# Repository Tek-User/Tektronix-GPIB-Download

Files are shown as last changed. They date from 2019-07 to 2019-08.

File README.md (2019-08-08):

# Tektronix-GPIB-Download
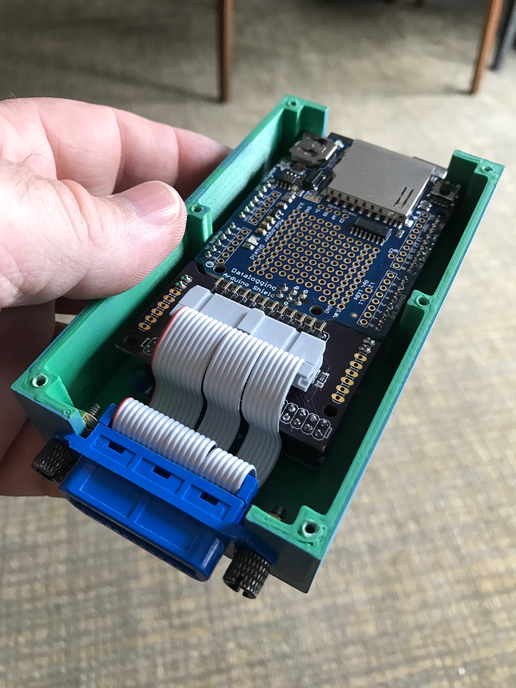
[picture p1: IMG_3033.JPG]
<a href="https://github.com/Tek-User/Tektronix-GPIB-Download/blob/master/IMG_3033.JPG"><br/></a>
 
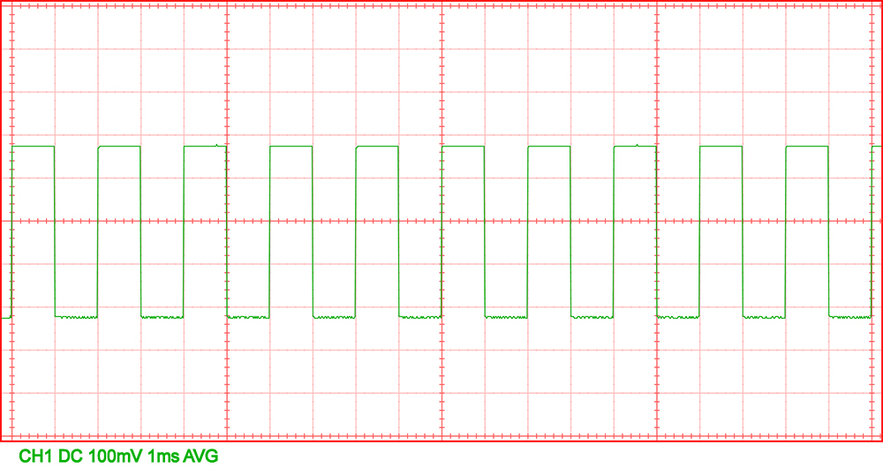
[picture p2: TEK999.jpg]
 <a href="https://github.com/Tek-User/Tektronix-GPIB-Download/blob/master/TEK999.jpg"><br/></a>

Software (and hardware) to allow copying your oscilloscope display directly to a flash drive using an Arduino Mega256

This purpose of this project is to create an inexpensive, and simple-to-build device which attaches to Tektronix 2430, 2430A, 2432, and 2440 digital storage oscilloscopes via GPIB interface to allow the user to download the displayed trace(s) to a flash drive without the need for a computer to be attached to the oscilloscope.  No hardware beyond the device and a GPIB cable are required.  The downloaded file on the flash drive is a vector graphics file type (SVG) which can be viewed and printed using readily available free software, even most web browsers.  

An Arduino (or clone) Mega2560 is required as the smaller devices do not have enough I/O pins to do the job properly.

The program interfaces to the oscilloscope front panel user-interface buttons.  It will save the displayed traces to a SVG file along with the volts/div and sec/div settings.  All 1024 data points are stored in the vector graphics file.

Control menus allow storing the trace(s), setting date/time/filename.

About 11% of the arduino flash is used, and 2K of the 8K ram is used allowing ample space for additions and modifications of the code to suit individual needs.  

The RTC and SD functions are provided by the Adafruit SD datalogging shield:
https://tinyurl.com/yyhj2fle

The device uses a custom "mini-shield" to connect to the Arduino Mega double row expansion connector, and provides a 24 pin (2x12) connector to go to a GPIB connector.  The link to the custom PCB on OSHPARK is :
https://oshpark.com/shared_projects/mtz1Vv3A

To build the GPIB mini-shield use sixteen 470 ohm 1206 size SMT resistors, a 2x18 straight male header (for the Arduino expansion header), and a 2x12 right angle (or straight) male header for the GPIB connector, and two 1x2 male headers. The 1x2 headers only provide some extra stability for the board in its attachment to the Arduino Mega.  If you use feed-through stacking headers, you can add more shields on top of this one.

An enclosure is able to be 3D printed.  The enclosure design (STL file type) is included in this project.  There are two separate files, one being the top and one being the bottom of the enclosure.  Some final fine-tuning of the enclosure is likely to be needed to get a perfect fit.  Use a fine file intended for woodworking.  In some places sandpaper will work well too.

Photos are included of the project (the enclosure, and resistor location on the mini-shield PCB are slightly different from the final designs in this project).  There is also a photo of an SVG file which has been converted to a raster JPG to display here.

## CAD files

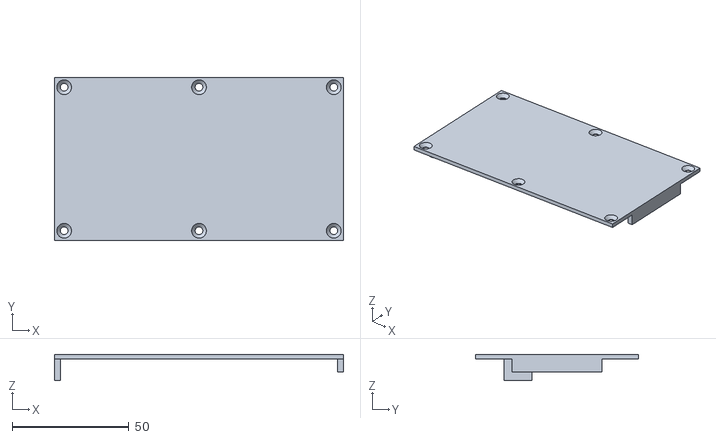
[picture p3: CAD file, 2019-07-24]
Arduino_GPIB_Box-top.stl
124.0 x 69.9 x 11.2

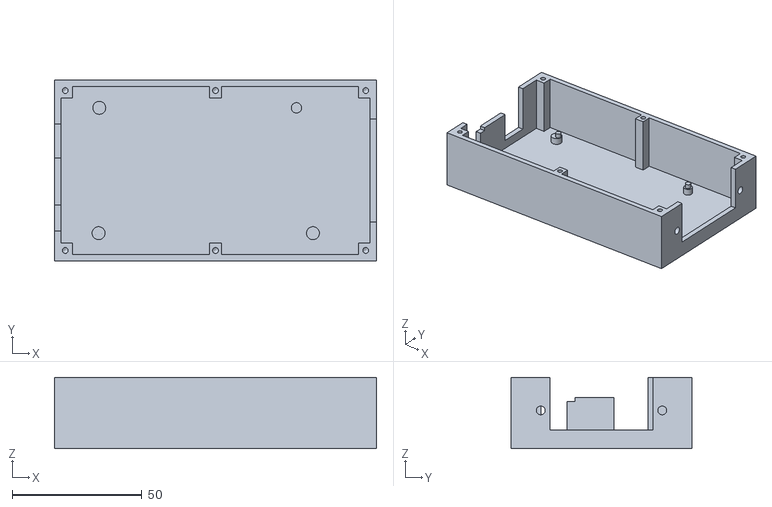
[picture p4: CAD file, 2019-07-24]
Arduino_GPIB_Box-bottom.stl
124.0 x 69.9 x 27.4

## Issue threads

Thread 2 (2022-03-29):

PCB layout differs from photo

algavrik, 2022-03-29:
PCB layout on OSHPARK differs from the real photo of PCB in the project. On OSHPARK PCB resistors are on the bottom side (arduino) of the board, but on the real photo I can see resistors on the top side of PCB (GPIB). Can you clarify?

Tek-User, 2022-03-29:
I will check.  It has been a couple of years since I worked with this.

-Tony

Sent from my 1837 Babbage Analytical Engine

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

Tek-User, 2023-11-01:
The through hole resistors can be placed on either side.   For simplicity during design I drew everything on the same side but for construction they can be placed on either side

Closed 2023-11-01.

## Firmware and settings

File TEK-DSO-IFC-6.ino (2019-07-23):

#include <avr/pgmspace.h>
#include <stdlib.h>
#include <inttypes.h>
#include <stdint.h>
#include <stdbool.h>
#include "GPIB.h"
#include "Tek_Interface.h"
#include "SVG.h"
#include "Arduino.h"
#include "RTC.h"
#include "EEP.h"
#include <SD.h>
#include <SPI.h>


/*This code will interface to the scope and wait for a SRQ.  It assumes it is ONLY connected to one scope and
 * nothing else.  It does not poll "EVT?"   It simply uses a loop reading the SRQ signal and when it is asserted (LOW)
 * it will read the event and take appropriate action.
 * 
 * There are 5 buttons that are able to be used: event code 450-454 inclusive
 * 1:  Save displayed waveforms to SVG
 * 2:  unused:  Maybe something like FFT
 * 3:  unused:  Maybe to save the front panel setup
 * 4:  unused:  Maybe something like recall the front panel setup
 * 5:  unused:  Use it for a hard reboot of the arduino
 * 
 *   This will not use the switches on the modified SONY-TEKTRONIX unit: the box is passive 
 *   This allows essentially ANY ARDUINO to be used for the GPIB interface as long as it can also use an SD card somehow.
 *   I think that NANO types don't have enough IO pins for full GPIB interface plus SD
 */


/*   Assumes the scope is at address #1! */


// TODO:  have errors printed to the scope screen instead of to the serial port


//extern char data_buffer[];  //defined in Tek_Interface module
extern RTC_PCF8523 rtc;



void setup() {

  
  bool wait_for_scope_boot = false;
  Serial.begin(115200);

 
  Serial.print(F("checking bus"));
  while (!GPIBCheck()) {   //check the GPIB Bus
      //TODO:  send message to 7-segments "SCOP" to indicate no scope present.  OR scroll "NO SCOPE" on the display
      delay(1000);
      Serial.print(F("."));
      wait_for_scope_boot = true;
  }
  Serial.println(F(" Bus OK"));
  

  //if the bus was not on-line when first tested, then the scope is booting up
  // and we need to it for the scope to complete its own initialization 
  if (wait_for_scope_boot)
  {
      Serial.println(F("Scope Boot Delay...30 sec"));
    for (int i=0; i<30;i++) //perform N loops of a 1 second delay
    {
      delay(1000);  //delay 1 second
    }
  }


  EEP_Init();
  RTC_setup();

  DateTime now = rtc.now();
    Serial.print(now.year(), DEC);
    Serial.print('/');
    Serial.print(now.month(), DEC);
    Serial.print('/');
    Serial.println(now.day(), DEC);

    Serial.print(now.hour(), DEC);
    Serial.print(':');
    Serial.print(now.minute(), DEC);
    Serial.print(':');
    Serial.print(now.second(), DEC);
    Serial.println();

    
  tek_Setup();

  checkID(); //TODO: use this check to stop further processing?
  introScreen();
  
  tek_Menu(1); 



  //testDataPins();
  //testSPI();
}




//******************************************************************************
void loop() {
  uint16_t event;


  event = 0;

#ifdef USE_SRQ  
//  Serial.println(F("wait for SRQ"));

  while (WaitForSRQ(0, 0xFFFE));  //returns a 1 if timeout occurs.  Keep polling SRQ until it is asserted (LOW): returns before timeout with a value of zero.
  
//    if (SRQ_PIN & SRQ_BIT) Serial.print(F("SRQ NOT ASSERTED (high)"));
//    else Serial.print(F("SRQ IS ASSERTED (low)"));
  event = GetEvent_SRQ();
  if (event) 
  {
    Serial.print(F("Event occurred:"));
    Serial.println(event);
    processEvent(event);
  }
  //no delays: process SRQs as fastr as possible

#else //use polling method
  event = GetEvent();
  if (event) 
  {
    Serial.print(F("Event occurred:"));
    Serial.println(event);
    processEvent(event);
  }
  else delay(1000); //if there is an event read, then don't delay reading the next one in case they are stacked up

#endif
 
}  //end of loop









//*********************************************************
//*
//*  Handle an incoming event
//*     Most will just get ignored!
//*
//*********************************************************
void processEvent(uint16_t evnt)
{
  // main menu [0] = save svg/hide/x/settings/reset cpu
  // settings menu [1] = date/time/x/x/back
  static uint8_t MenuState = 0;

  switch (MenuState)
  {
    case 0: //main menu
     switch (evnt)
     {
       case 652:  //hide display button pressed
         tek_Menu(MenuState, 1);  //show the menu and force it to be displayed
         break;
       case 450:  //Left hand-most button pressed:  save SVG
         processSVG();
         break;
       case 451:   //hide or unhide the menubar
         tek_Menu(MenuState);  //toggle the displayed state of the menu
         break;
       case 452:
         break;
       case 453:
         MenuState = 1;
         tek_Menu(MenuState,1); //show the new menu and force it to be displayed
         break;
       case 454: //maybe use this to hard reset the arduino
         //hideMenu();
         resetCPU();
         break;
      }  //end switch evnt
      break;

    case 1: //settings menu
     switch (evnt)
     {
       case 652:  //hide display button pressed
         tek_Menu(MenuState, 1);  //show the menu and force it to be displayed
         break;
       case 450:  //set date
         //call date setting function
         RTC_Date();
         tek_Menu(MenuState, 1);  //show the menu and force it to be displayed
         break;
       case 451: //set time
         RTC_Time();
         tek_Menu(MenuState, 1);  //show the menu and force it to be displayed
         break;
       case 452: //set file name
         tek_SetFileName();
         tek_Menu(MenuState, 1);  //show the menu and force it to be display
         break;
       case 453:
         break;
       case 454: //move up one menu state
         MenuState--;
         if (MenuState == 0xFF) MenuState = 0; //prevent undershooting menustate accidentally: shouldn't ever be possible
         tek_Menu(MenuState,1); //show the new menu and force it to be displayed
         break;
      }  //end switch evnt
      break;
  }  //end switch MenuState  
}




void resetCPU(void)
{
  //This does a software-only reset without resetting ALL the hardware
  //void(* resetFunc) (void) = 0;//declare reset function at address 0
  //resetFunc(); //call reset 

  //This does a hardware reset like a power-up reset:  All registers ad pins are cleared

  noInterrupts();
  __asm("wdr");
  WDTCSR = (1<<WDCE) | (1<<WDE);
  WDTCSR = (1<<WDE);
  while (1);
}












void testDataPins(void)
{
    Serial.println(F("testing pins: data0, gpib PIN 1"));
    //test the data pins
     while (Serial.available()) Serial.read();   //flush the serial channel
     while (!Serial.available()) {
        GPIBRelease( &DATA0_PORT,&DATA0_DDR, DATA0_BIT);
        delay(10);
        GPIBAssert( &DATA0_PORT,&DATA0_DDR, DATA0_BIT);
        delay(10);
     }

     while (Serial.available()) Serial.read();   //flush the serial channel

     Serial.println(F("testing pins: data1, GPIB PIN 2"));
     while (!Serial.available()) {
        GPIBRelease( &DATA1_PORT,&DATA1_DDR, DATA1_BIT);
        delay(10);
        GPIBAssert( &DATA1_PORT,&DATA1_DDR, DATA1_BIT);
        delay(10);
     }
     while (Serial.available()) Serial.read();   //flush the serial channel

     Serial.println(F("testing pins: data2, GPIB PIN 3"));
      while (!Serial.available()) {
        GPIBRelease( &DATA2_PORT,&DATA2_DDR, DATA2_BIT);
        delay(10);
        GPIBAssert( &DATA2_PORT,&DATA2_DDR, DATA2_BIT);
        delay(10);
     }
     while (Serial.available()) Serial.read();   //flush the serial channel

     Serial.println(F("testing pins: data3, GPIB PIN 4"));
     while (!Serial.available()) {
        GPIBRelease( &DATA3_PORT,&DATA3_DDR, DATA3_BIT);
        delay(10);
        GPIBAssert( &DATA3_PORT,&DATA3_DDR, DATA3_BIT);
        delay(10);
     }
     while (Serial.available()) Serial.read();   //flush the serial channel


     Serial.println(F("testing pins: data4, GPIB PIN 13"));
     while (!Serial.available()) {
        GPIBRelease( &DATA4_PORT,&DATA4_DDR, DATA4_BIT);
        delay(10);
        GPIBAssert( &DATA4_PORT,&DATA4_DDR, DATA4_BIT);
        delay(10);
     }
     while (Serial.available()) Serial.read();   //flush the serial channel

     Serial.println(F("testing pins: data5, GPIB PIN 14"));
     while (!Serial.available()) {
        GPIBRelease( &DATA5_PORT,&DATA5_DDR, DATA5_BIT);
        delay(10);
        GPIBAssert( &DATA5_PORT,&DATA5_DDR, DATA5_BIT);
        delay(10);
     }
     while (Serial.available()) Serial.read();   //flush the serial channel


     Serial.println(F("testing pins: data6, GPIB PIN 15"));
     while (!Serial.available()) {
        GPIBRelease( &DATA6_PORT,&DATA6_DDR, DATA6_BIT);
        delay(10);
        GPIBAssert( &DATA6_PORT,&DATA6_DDR, DATA6_BIT);
        delay(10);
     }
     while (Serial.available()) Serial.read();   //flush the serial channel


     Serial.println(F("testing pins: data7, GPIB PIN 16"));
     while (!Serial.available()) {
        GPIBRelease( &DATA7_PORT,&DATA7_DDR, DATA7_BIT);
        delay(10);
        GPIBAssert( &DATA7_PORT,&DATA7_DDR, DATA7_BIT);
        delay(10);
     }
     while (Serial.available()) Serial.read();   //flush the serial channel


     Serial.println(F("testing pins: EOI, GPIB PIN 5"));
     while (!Serial.available()) {
        GPIBRelease( &EOI_PORT,&EOI_DDR, EOI_BIT);
        delay(10);
        GPIBAssert( &EOI_PORT,&EOI_DDR, EOI_BIT);
        delay(10);
     }
     while (Serial.available()) Serial.read();   //flush the serial channel


     Serial.println(F("testing pins: DAV, GPIB PIN 6"));
     while (!Serial.available()) {
        GPIBRelease( &DAV_PORT,&DAV_DDR, DAV_BIT);
        delay(10);
        GPIBAssert( &DAV_PORT,&DAV_DDR, DAV_BIT);
        delay(10);
     }
     while (Serial.available()) Serial.read();   //flush the serial channel


     Serial.println(F("testing pins: NRFD, GPIB PIN 7"));
     while (!Serial.available()) {
        GPIBRelease( &NRFD_PORT,&NRFD_DDR, NRFD_BIT);
        delay(10);
        GPIBAssert( &NRFD_PORT,&NRFD_DDR, NRFD_BIT);
        delay(10);
     }
     while (Serial.available()) Serial.read();   //flush the serial channel


     Serial.println(F("testing pins: NDAC, GPIB PIN 8"));
     while (!Serial.available()) {
        GPIBRelease( &NDAC_PORT,&NDAC_DDR, NDAC_BIT);
        delay(10);
        GPIBAssert( &NDAC_PORT,&NDAC_DDR, NDAC_BIT);
        delay(10);
     }
     while (Serial.available()) Serial.read();   //flush the serial channel


     Serial.println(F("testing pins: IFC, GPIB PIN 9"));
     while (!Serial.available()) {
        GPIBRelease( &IFC_PORT,&IFC_DDR, IFC_BIT);
        delay(10);
        GPIBAssert( &IFC_PORT,&IFC_DDR, IFC_BIT);
        delay(10);
     }
     while (Serial.available()) Serial.read();   //flush the serial channel


     Serial.println(F("testing pins: SRQ, GPIB PIN 10"));
     while (!Serial.available()) {
        GPIBRelease( &SRQ_PORT,&SRQ_DDR, SRQ_BIT);
        delay(10);
        GPIBAssert( &SRQ_PORT,&SRQ_DDR, SRQ_BIT);
        delay(10);
     }
     while (Serial.available()) Serial.read();   //flush the serial channel


     Serial.println(F("testing pins: ATN, GPIB PIN 11"));
     while (!Serial.available()) {
        GPIBRelease( &ATN_PORT,&ATN_DDR, ATN_BIT);
        delay(10);
        GPIBAssert( &ATN_PORT,&ATN_DDR, ATN_BIT);
        delay(10);
     }
     while (Serial.available()) Serial.read();   //flush the serial channel


     Serial.println(F("testing pins: REN, GPIB PIN 17"));
     while (!Serial.available()) {
        GPIBRelease( &REN_PORT,&REN_DDR, REN_BIT);
        delay(10);
        GPIBAssert( &REN_PORT,&REN_DDR, REN_BIT);
        delay(10);
     }
     while (Serial.available()) Serial.read();   //flush the serial channel
}



void testSPI(void)
{
     Serial.println(F("Testing SPI MOSI"));
     pinMode(PIN_SPI_MOSI,OUTPUT);
     while (!Serial.available()) {
        digitalWrite(PIN_SPI_MOSI, 1);
        delay(10);
        digitalWrite(PIN_SPI_MOSI, 0);
        delay(10);
     }
     pinMode(PIN_SPI_MOSI,INPUT);
     while (Serial.available()) Serial.read();   //flush the serial channel


     Serial.println(F("Testing SPI MISO"));
     pinMode(PIN_SPI_MISO,OUTPUT);
     while (!Serial.available()) {
        digitalWrite(PIN_SPI_MISO, 1);
        delay(10);
        digitalWrite(PIN_SPI_MISO, 0);
        delay(10);
     }
     pinMode(PIN_SPI_MISO,INPUT);
     while (Serial.available()) Serial.read();   //flush the serial channel


     Serial.println(F("Testing SPI SCK"));
     pinMode(PIN_SPI_SCK,OUTPUT);
     while (!Serial.available()) {
        digitalWrite(PIN_SPI_SCK, 1);
        delay(10);
        digitalWrite(PIN_SPI_SCK, 0);
        delay(10);
     }
     pinMode(PIN_SPI_SCK,INPUT);
     while (Serial.available()) Serial.read();   //flush the serial channel



     Serial.println(F("Testing SPI /CS"));
     pinMode(CS_PIN,OUTPUT);
     while (!Serial.available()) {
        digitalWrite(CS_PIN, 1);
        delay(10);
        digitalWrite(CS_PIN, 0);
        delay(10);
     }
     pinMode(CS_PIN,INPUT);
     while (Serial.available()) Serial.read();   //flush the serial channel
}

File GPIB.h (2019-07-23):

#ifndef GPIB_h
#define GPIB_h

#include <inttypes.h>
#include <stdint.h>
#include <stdbool.h>

//to make porting of NI488.1 code easier here are some macros
#define bd 1;
#define ibwrt(hw,arr,len) GPIBWriteData(arr,len,true)  //write data to the bus, hw value is not used: this controller device is assumed
#define ibcmd(hw,arr,len) GPIBWriteCmd(arr, len, true) //Write a command to the bus, hw value is not used: this controller device is assumed
//#define ibrd(hw,arr,len) Read_Data()  //Puts data into standard data_buffer array, hw value is not used: this controller device is assumed
#define ibrd(hw,arr,len) GPIBGetData(arr, len, 10000)  //Puts data into standard data_buffer array, hw value is not used: this controller device is assumed

// PIN DEFINITIONS
#define _HIGH    1
#define _LOW     0
#define _ASSERTED  0
#define _RELEASED  1

//0=C4    4=C2
//1=c1    5=C1
//2=C    6=D3
//3=D4    7=D5

//NOTE:  THE UNO AND NANO HAVE ONLY 20 FREE I/O PINS:
//       THE SPI INTERFACE FOR THE SD CARD USES 4 PINS, AND THE H/W SERIAL PORT USED 2 MORE, LEAVING 14
//       THE GPIB BUS USES 16 PINS TOTAL: 8 DATA PINS, and DAV, NRFD, NDAC, EOI, ATN FOR 13 PINS ABSOLUTELY REQUIRED
//       THERE ARE ALSO REN, IFC, SRQ PINS. 
//
//       THIS SOFTWARE IS DESIGNED TO USE THE SRQ SIGNAL FOR WHEN THE SCOPE WANTS ATTENTION.  IT IS POSSIBLE TO
//       POLL THE SCOPE AND NOT USE THE SRQ SIGNAL AT ALL. BUT FOR THIS SOFTWARE, SRQ IS REQUIRED: 14 ESSENTIAL I/O PINS
//
//       THE IFC SIGNAL IS NICE TO HAVE SO THE SCOPE GPIB INTERFACE CAN BE CLEARED IF NECESSARY.  THIS DOES NOT SEEM TO BE VITAL.
//       THIS SOFTWARD DOES NOT USE THE REN SIGNAL.

//       SO THIS SOFTWARE, AS WRITTEN, USES A MINUMUM OF 14 I/O PINS FOR COMMUNICATING TO THE SCOPE AND 4 FOR COMMUNICATING TO
//       THE SD CARD: FOR A TOTAL OF 18 I/O PINS.  PINS WHICH HAVE EXTERNAL PULL UP/DOWN RESISTORS (LIKE THE LED PIN(S))
//       ARE NOT EASILY USED FOR GPIB OR SD FUNCTIONS EXCEPT FOR THE SD'S "CS" AND "SCK" SIGNALS. CS/SCK SIGNALS COULD TOLERATE
//       AN LED, MOST LIKELY.
//
//       I THINK IT MAY BE BARELY POSSIBLE TO USE A NANO FOR THIS PROJECT.  A MEGA IS DEFINITELY CAPABLE, WHICH IS WHAT I USE.


//  THESE UNO/NANO PIN DEFINITIONS ARE _N_O_T_ COMPATIBLE WITH USING AN SD CARD WITH FULL GPIB!
//  IT IS LIKELY THAT THE 13 ESSENTIAL GPIB SIGNALS, PLUS SRQ, AND THE 4 SPI SIGNALS CAN BE SUPPORTED ON THE NANO
//  BUT THESE DEFINITIONS ARE NOT GOING TO BE CORRECT!!!!!

#if defined (ARDUINO_AVR_UNO) || defined (ARDUINO_AVR_NANO)
#warning "UNO or Nano"
#error "NANO/UNO is not currently supported"
    //#Define DATA0 C.4
    #define DATA0_PORT PORTC
    #define DATA0_PIN PINC
    #define DATA0_DDR DDRC
    #define DATA0_BIT _BV(4)

    //#Define DATA1 C.3
    #define DATA1_PORT PORTC
    #define DATA1_PIN PINC
    #define DATA1_DDR DDRC
    #define DATA1_BIT _BV(3)

    //#Define DATA2 C.2
    #define DATA2_PORT PORTC
    #define DATA2_PIN PINC
    #define DATA2_DDR DDRC
    #define DATA2_BIT _BV(2)

    //#Define DATA3 C.1
    #define DATA3_PORT PORTC
    #define DATA3_PIN PINC
    #define DATA3_DDR DDRC
    #define DATA3_BIT _BV(1)

    //#Define DATA4 D.2
    #define DATA4_PORT PORTD
    #define DATA4_PIN PIND
    #define DATA4_DDR DDRD
    #define DATA4_BIT _BV(2)

    //#Define DATA5 D.3
    #define DATA5_PORT PORTD
    #define DATA5_PIN PIND
    #define DATA5_DDR DDRD
    #define DATA5_BIT _BV(3)

    //#Define DATA6 D.4
    #define DATA6_PORT PORTD
    #define DATA6_PIN PIND
    #define DATA6_DDR DDRD
    #define DATA6_BIT _BV(4)

    //#Define DATA7 D.5
    #define DATA7_PORT PORTD
    #define DATA7_PIN PIND
    #define DATA7_DDR DDRD
    #define DATA7_BIT _BV(5)
    
    //#Define REN   D.6
    #define REN_PORT PORTD
    #define REN_PIN PIND
    #define REN_DDR DDRD
    #define REN_BIT _BV(6)
    
    //#Define ATN   D.7
    #define ATN_PORT PORTD
    #define ATN_PIN PIND
    #define ATN_DDR DDRD
     #define ATN_BIT _BV(7)

    //#Define SRQ   B.0
    #define SRQ_PORT PORTB
    #define SRQ_PIN PINB
    #define SRQ_DDR DDRB
    #define SRQ_BIT _BV(0)
  
    //#Define IFC   B.1
    #define IFC_PORT PORTB
    #define IFC_PIN PINB
    #define IFC_DDR DDRB
    #define IFC_BIT _BV(1)

    //#Define NDAC  B.2
    #define NDAC_PORT PORTB
    #define NDAC_PIN PINB
    #define NDAC_DDR DDRB
    #define NDAC_BIT _BV(2)

    //#Define NRFD  B.3       ALSO USED BY SPI'S MISO SIGNAL
    #define NRFD_PORT PORTB
    #define NRFD_PIN PINB
    #define NRFD_DDR DDRB
    #define NRFD_BIT _BV(3)

    //#Define DAV   B.4       ALSO USED BY SPI'S MOSI SIGNAL
    #define DAV_PORT PORTB
    #define DAV_PIN PINB
    #define DAV_DDR DDRB
    #define DAV_BIT _BV(4)

    //#Define EOI   C.0
    #define EOI_PORT PORTC
    #define EOI_PIN PINC
    #define EOI_DDR DDRC
    #define EOI_BIT _BV(0)

    //#Define LED   B.5         ALSO USED BY SPI'S SCK SIGNAL
    #define LED_PORT PORTB
    #define LED_PIN PINB
    #define LED_DDR DDRB
    #define LED_BIT _BV(5)

    //#Define FREE  C.5
    #define CS_PIN 10   //using the SD shield, it uses pin 10 for the card select.
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

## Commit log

2019-07-23 Add files via upload
    Updated Arduino files which allow full control from the scope user panel. New functions are to set the RTC date and time. Also a new function allws you to set the file name stub in the form of XXXXXn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
2019-07-24 Add files via upload
    STL files for 3D printer to make the enclosure
    [Arduino_GPIB_Box-bottom.stl, Arduino_GPIB_Box-top.stl]
